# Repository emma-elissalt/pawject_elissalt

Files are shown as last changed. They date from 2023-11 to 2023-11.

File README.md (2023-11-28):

# pawject_elissalt
Projet Proto

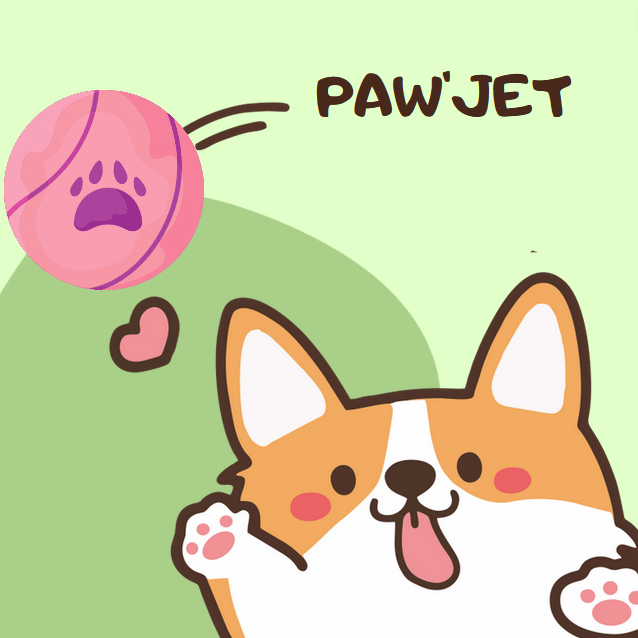
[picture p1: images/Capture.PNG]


Nous sommes Marie ARNAUD, Adrien COVAREL & Emma ELISSALT 

## Problématique
  
Comment optimiser les besoins d'exercice, de stimulation mentale et d'interaction autonome, afin d’éviter l’ennui de votre chien, tout en offrant une solution pratique pour vous, propriétaires ?  

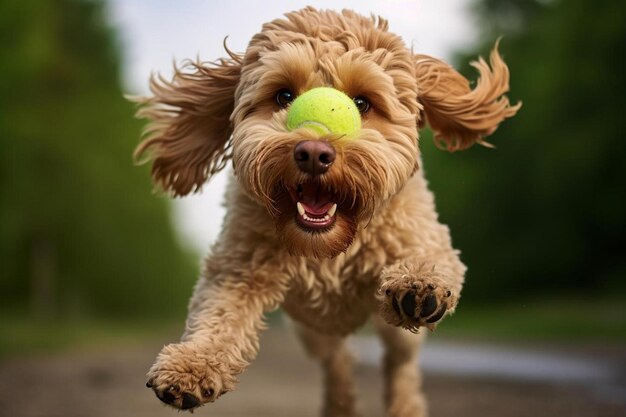
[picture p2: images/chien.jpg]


## Notre projet
  
Nous avons mis en place un robot (fixe) capable de lancer la balle de votre chien. Il marche avec une application mobile connectée en Bluetooth au robot qui sert à lancer la balle lorsque l’utilisateur appuie sur le bouton.  

plot
  
## Mise en route

Dans un premier temps il faut se connecter a notre application sur MIT App Inventor, PawJet (*PawJet.aia*). Pour cela, il suffit d'appuyer sur le bouton *connexion ble*. Puis dans la liste *devices* sélectionner le bluetooth *EMMA&MARIE* qui correspond a celui présent sur notre carte ESP32. Si nous sommes bien connectés alors la checkbox passe à *true*.   
Pour lancer la balle il faut ensuite appuyer sur le bouton *play with me*.   
Pour se déconnecter il faut appuyer sur *deconnexion ble*.  
  
Il faut ensuite ouvrir le logiciel *Arduino IDE 2* sur l'ordinateur portable et run le code *code_app_ble_test.ino*. Ce code permet de verifier qu'il y ai bien une balle dans le robot et s'il n'y a pas de chien (ou obstacle) dans le champ de tir lorsque l'utilisateur fait une demande de lancement de la balle.   
Si toutes ces conditions sont réunies alors le code print dans le *serial* un *1* pour indiquer que le lancer peut avoir lieu. Dans le cas contraire, on envoie rien. 
  
Maintenant il reste juste a activer les moteurs *Dynamixel* en se servant de *ROS2*. Pour cela nous avons crée un workspace *pawject_wsv2*. Dans le package *control_motor* se trouve le noeud *serialport.py* qui sert à publish sur le port série de la esp32 (endroit ou nous envoyons le 1 quand on peut tirer). Le noeud *control.py* sert a subscribe (recuperer l'information du publish) sur le noeud précédent pour commander les moteurs afin de pouvoir lancer la balle. Un moteur est en *control vitesse* pour mettre en tension le ressort en enroulant un fil. Le deuxième moteur est en *control position* pour déclencher le lancer. Ce dernier moteur fait glisser le support où est enroulé le fil afin de le dérouler d'un coup, permettant ainsi au ressort de se tendre et de propulser la balle. 
  
Voici comment communique nos noeuds :   

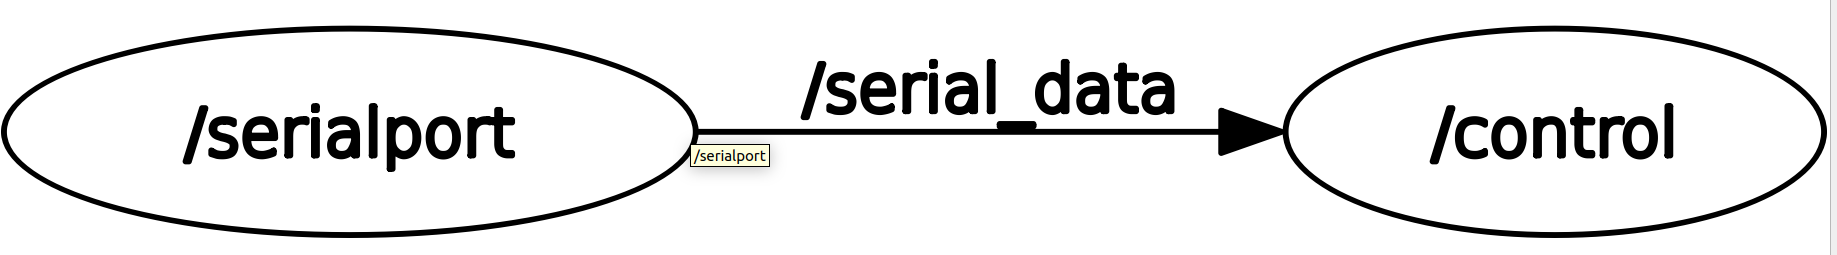
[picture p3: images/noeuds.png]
  

Dans un terminal, après avoir sourcé ros2 et s'etre mis dans le workspace, il suffit de lancer la commande *ros2 run control_motor serialport* et la commande *ros2 run control_motor control* dans un second terminal.  
Dans le premier terminal on peut voir ce qu'il y a comme information envoyée par l'ESP32 sur le serial.  
Dans le second terminal on peut voir les commandes exécutées en fonction des informations reçue par le topic *serial_data* (on souscrit a ce topic).

Voici le résultat dans les terminaux lorsque l'on lance les noeuds : 

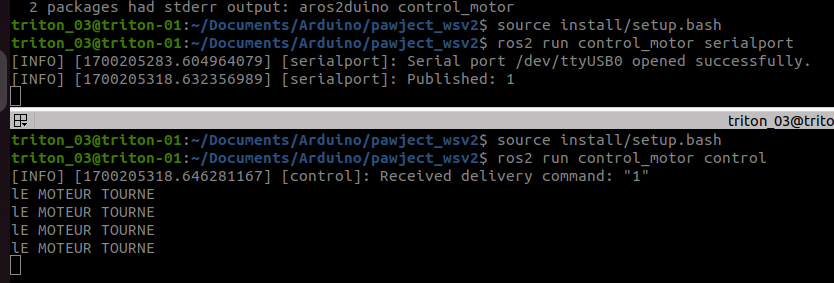
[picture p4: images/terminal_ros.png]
  

## Architecture 

Voici l'architecture (hardware) de notre système : 
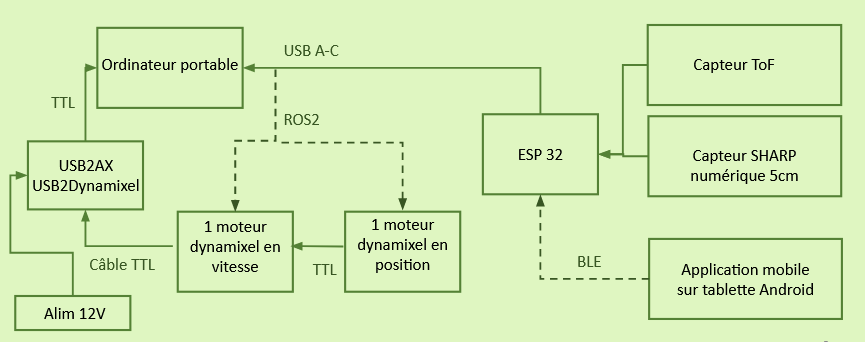
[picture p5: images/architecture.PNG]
  

## Vidéo explicative 

Voici une vidéo de démonstration pour notre prototype : https://youtu.be/jBiW0mczfOc?feature=shared

## Poster / PowerPoint

Dans le dossier poster/powerpoint vous pouvez trouver un poster et une présentation powerpoint explicative de notre projet. 

## Conclusion 
Ce projet nous a permis de mettre en ouevre un prototype répondant à une problématique. Nous avons pu lors de la réalisation de ce prototype mettre en pratique énormément de compétences vu tout au long de nos études. Que ça soit du bas ou du haut niveau dans l'architecture, comme avec la maîtrise des servo moteurs Dynamixal sous ROS2, la communication en BLE entre une application mobile et une carte ESP32, ou alors plus simplement l'utilsation de capteurs de distance.   
C'etait vraiment interresant d'être libre dans le sujet et quasiment en autonomie pour sa réalisation. 

👍

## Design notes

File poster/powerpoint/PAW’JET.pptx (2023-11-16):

## PAW’JET

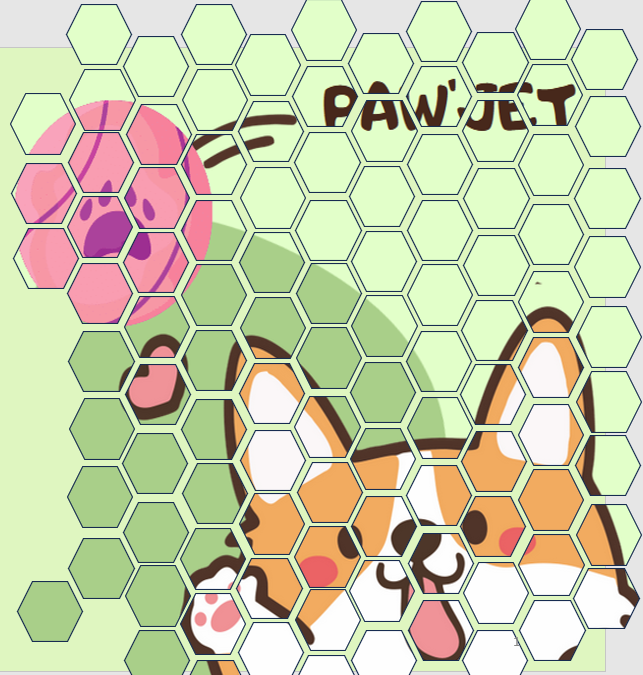
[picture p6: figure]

Presenté par
Marie Arnaud, Adrien Covarel & Emma Elissalt

## Problématique

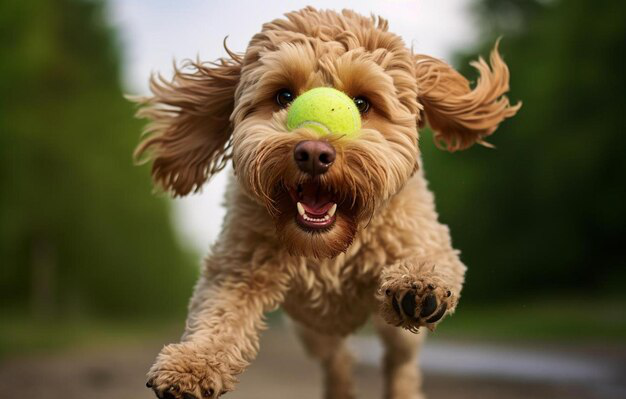
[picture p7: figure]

Comment optimiser les besoins d'exercice, de stimulation mentale et d'interaction autonome, afin d’éviter l’ennui de votre chien, tout en offrant une solution pratique pour vous, propriétaires ?

## Présentation de la solution L’architecture

Ordinateur portable

TTL

Capteur ToF

USB A-C

ROS2

USB2AX
USB2Dynamixel

ESP 32

Capteur SHARP numérique 5cm

Câble TTL

1 moteur dynamixel en vitesse

1 moteur dynamixel en position

TTL

BLE

Application mobile sur tablette Android

Alim 12V

## Perspectives d’évolution

1

2

2

3

## Perspectives d’évolution

- Faire un système embarqué en utilisant des batteries et une carte Raspberry PI
- Avoir un deuxième mode de jeu « automatique ». Le robot lancera une balle dès qu’il en détecte une

1

2

2

3

## Perspectives d’évolution

- Faire un système embarqué en utilisant des batteries et une carte Raspberry PI
- Avoir un deuxième mode de jeu « automatique ». Le robot lancera une balle dès qu’il en détecte une

1

- Possibilité de lancer une balle uniquement lorsqu’il s’agit de celle de notre chien. Utilisation d’une puce RFID
- Basse tournante a 360 degrés pour lancer dans toutes les directions. Télécommander avec l’application

2

3

## Perspectives d’évolution

- Faire un système embarqué en utilisant des batteries et une carte Raspberry PI
- Avoir un deuxième mode de jeu « automatique ». Le robot lancera une balle dès qu’il en détecte une

1

- Possibilité de lancer une balle uniquement lorsqu’il s’agit de celle de notre chien. Utilisation d’une puce RFID
- Basse tournante a 360 degrés pour lancer dans toutes les directions. Télécommander avec l’application

2

- Distribuer une croquette lorsque le chien remet la balle dans l’entonnoir. Afin d’inciter le chien à le faire et d’économiser des efforts pour le maître.

3

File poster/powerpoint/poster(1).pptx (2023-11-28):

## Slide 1

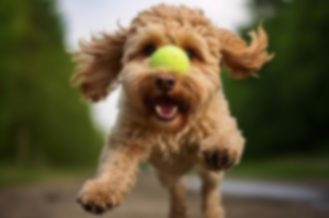
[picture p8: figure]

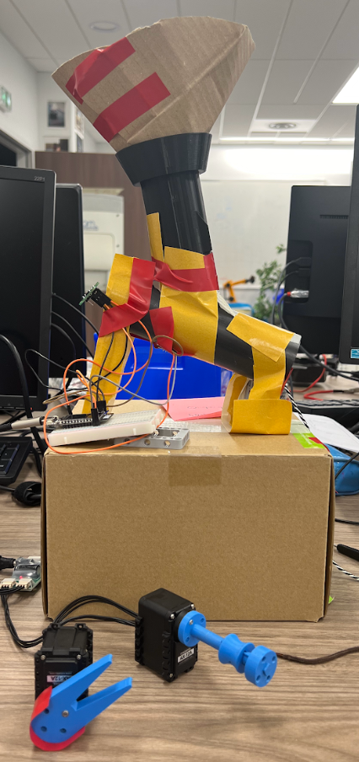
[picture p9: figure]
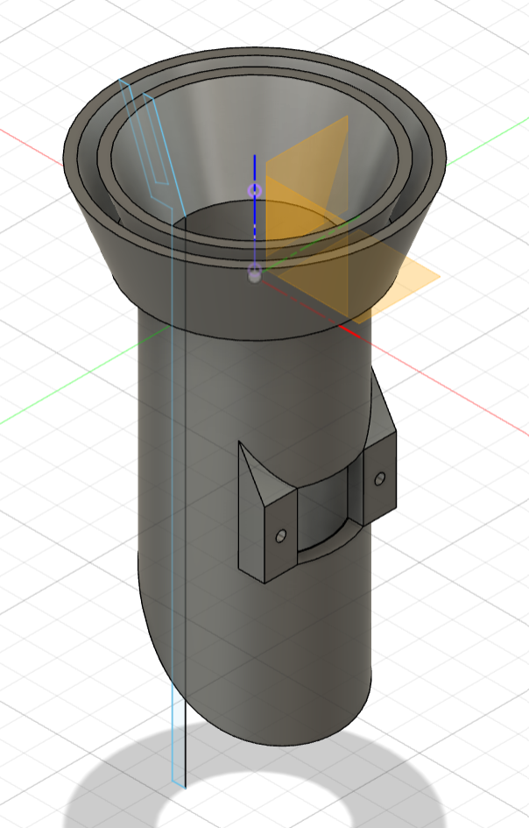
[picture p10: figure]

PAW’JET
Lanceur de balle pour chien

Comment optimiser les besoins d'exercice, de stimulation mentale et d'interaction autonome, afin d’éviter l’ennui de votre chien, tout en offrant une solution pratique pour vous, propriétaires ?

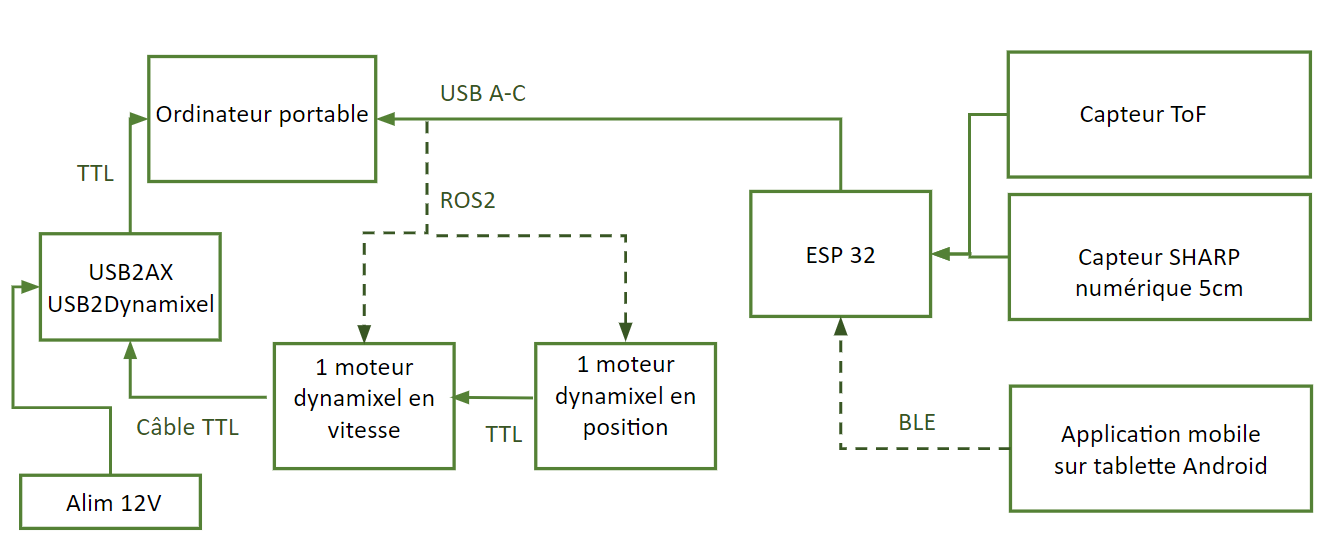
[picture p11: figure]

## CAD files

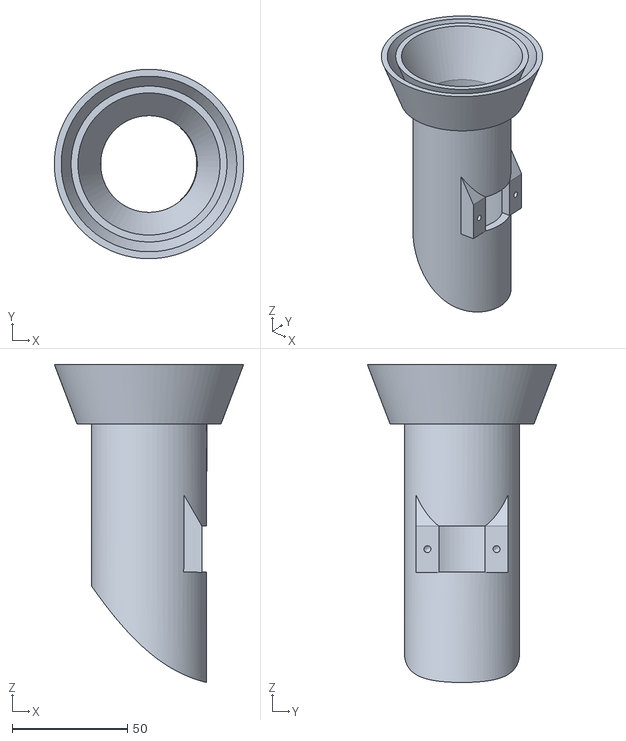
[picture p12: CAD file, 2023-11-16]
Impression 3D/entonnoir v17.stl
82.2 x 82.3 x 138.1

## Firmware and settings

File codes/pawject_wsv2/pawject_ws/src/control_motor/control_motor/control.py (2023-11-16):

import rclpy
import time
from rclpy.node import Node
from std_msgs.msg import String
import dynamixel_sdk as sdk
from geometry_msgs.msg import Point
from random import randint
class Control(Node):
    def __init__(self):
        super().__init__('control')
        self.subscription = self.create_subscription(String,'/serial_data',self.listener_callback,10)
        self.subscription  # prevent unused variable warning

        # Setup Dynamixel SDK
        self.portHandler = sdk.PortHandler('/dev/ttyACM0')
        self.packetHandler = sdk.PacketHandler(1.0)
        self.DXL_ID = 0  # Dynamixel ID : 1
        self.DXL_ID_2 = 1  # Dynamixel ID : 1

        # Open port
        if not self.portHandler.openPort():
            self.get_logger().error("Failed to open the port")
            exit()

        # Set baudrate
        if not self.portHandler.setBaudRate(1000000):
            self.get_logger().error("Failed to change the baudrate")
            exit()

        self.ADDR_MX_GOAL_POSITION = 30 
        self.ADDR_MX_SPEED = 32
       

    def listener_callback(self, msg):
        self.get_logger().info('Received delivery command: "%s"' % msg.data)
        # Activate servomotor movement here
        self.POSITION_VALUE = 500
        self.move_servo(self.POSITION_VALUE,self.DXL_ID,self.ADDR_MX_SPEED)
        time.sleep(1.5)
        self.move_servo(0,self.DXL_ID,self.ADDR_MX_SPEED)
        time.sleep(2)
        self.move_servo(600,self.DXL_ID_2,self.ADDR_MX_GOAL_POSITION)
        time.sleep(1.5)
        self.move_servo(400,self.DXL_ID_2,self.ADDR_MX_GOAL_POSITION)
            
    def move_servo(self, position, ID, adresse):
        dxl_comm_result, dxl_error = self.packetHandler.write2ByteTxRx(self.portHandler, ID, adresse, position)
        # dxl_comm_result, dxl_error = self.packetHandler.write2ByteTxRx(self.portHandler, self.DXL_ID_2, self.ADDR_MX_GOAL_POSITION, position)

        print('lE MOTEUR TOURNE')
        if dxl_comm_result != sdk.COMM_SUCCESS:
            self.get_logger().error(self.packetHandler.getTxRxResult(dxl_comm_result))
        elif dxl_error != 0:
            self.get_logger().error(self.packetHandler.getRxPacketError(dxl_error))

        # You might want to read the position back, or add more logic here

    def __del__(self):
        # Close port
        self.portHandler.closePort()


def main(args=None):
    rclpy.init(args=args)
    control= Control()

    try:
        rclpy.spin(control)
    except KeyboardInterrupt:
        print('Servo controller node stopped cleanly')
    except BaseException:
        print('Exception in servo controller:', file=sys.stderr)
        raise
    finally:
        control.destroy_node()
        rclpy.shutdown()

if __name__ == '__main__':
    main()

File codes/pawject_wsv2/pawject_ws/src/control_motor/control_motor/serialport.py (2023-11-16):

import rclpy
from rclpy.node import Node
from std_msgs.msg import String
import serial


class SerialPort(Node):
    def __init__(self):
        super().__init__('serialport')
        self.publisher = self.create_publisher(String,'serial_data',10)
        self.serial_port = "/dev/ttyUSB0"
        self.baudrate = 115200
        self.timeout = 1     
        self.read_serial()
        
    def read_serial(self):       
        # try:
        ser = serial.Serial(self.serial_port, self.baudrate, timeout=self.timeout)
        self.get_logger().info(f"Serial port {self.serial_port} opened successfully.")

        while rclpy.ok():
            # Read data from the serial port
            data = ser.readline().decode('utf-8').strip()

            # Publish the received data to the ROS 2 topic
            if data:
                msg = String()
                msg.data = data
                self.publisher.publish(msg)
                self.get_logger().info(f"Published: {data}")

        # except serial.SerialException as e:
        #     self.get_logger().error(f"Error: {e}")
        # finally:
        #     if ser.is_open:
        #         ser.close()
        #         self.get_logger().info("Serial port closed.")

        

def main(args=None):
    rclpy.init(args=args)


    serialport = SerialPort()

    try:
        rclpy.spin(serialport)
    except KeyboardInterrupt:
        print('Servo controller node stopped cleanly')
    except BaseException:
        print('Exception in servo controller:', file=sys.stderr)
        raise
    finally:
        serial_port.destroy_node()
        rclpy.shutdown()

if __name__ == "__main__":
    main()

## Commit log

2023-11-16 ajouts stl et arduino
    [entonnoir v17.stl]
2023-11-16 modification du readme et des dossiers
    [entonnoir v17.stl]
